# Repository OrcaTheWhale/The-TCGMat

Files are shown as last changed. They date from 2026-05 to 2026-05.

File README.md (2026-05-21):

# The-TCGMat
A mat that is designed for TCG! Well, mostly just One Piece TCG and Riftbound.

Notice:
Under "StepFiles", and in the Onshape document, certain parts have "O" at the end of their names. This means that part is optional. If  you would like to save on filament, then you can skip printing the optional parts.

I also assume you have jumper wires. If you don't, what are you doing.

**What is this?**

The TCGMat is a 3D - printable (and thick) mat that integrates LEDS and a screen into your TCG experience! With LED settings, you can turn change the color of your border, alongside the Leader/Legend card border. You can also pass your turn, turning the border leds to red!

The TCGMat has a few built in settings for basic level play, such as Riftbound settings, One Piece settings, and LED settings. 

It also contains **NO** screws, meaning it's literally attach-and-play.

**Why would I use this?**

Great question! Why would you? It IS 2kg of filament... But think about it! Just like the Zine page says, you can absolutely mog your opponent! Think about it. It's a tournament. Or a local game tournament. Your opponent takes out his cool art mat of DaVinci Starry Night Pikachu. And then, you whip out - this thick, 2kg piece of rectangle. Will people think you look stupid? Mmm, maybe. But then, they'll see the LED colors shine at the borders. They'll still think it's stupid, of course, but now, it looks _cool_ stupid. The amount of aura you'll have with the mat will provide a sense of dominance.

**How does this work?**

You take the parts and attach them, no screws needed. You link them using four or two link rectangles given in the CAD/StepFiles. 
For the code, well... It's built based off of pure hopes and dreams. It is about 800 lines of absolutely disgustingly unoptimized code. 
There are three buttons: On/Off, Config, and Action. On/Off is self explanatory. Config is for the settings, it allows scrolling through different options. Action selects those options.

**Why did I make this?**

Great question, reader! I made this to try communication between microcontrollers. Originally, the idea was to have two mats being able to connect to each other and share info, but I gave up on that idea after realising I would have to change... some things... But, the option is still there, if you want to try to go for it yourself.

The reference Transf- (it cut off) is for magnetic pogo pin connectors. You can check the schematic, but RX is labeled for you, if you are going for TX/RX communicaton. A resistor is also already placed on the TX line. If you want to try for communication, go for it!

But I also made this cause my friends play One Piece / Riftbound TCG. I, myself only play Riftbound, but I thought it'd be cooler to have more than one game option on the TCG Mat. I also have no idea how to play other TCG's, so that's why the only options are Riftbound and One Piece.

**For the TCG fans:**

Take a shower.

Zine Page!



PCB:





Schematic:


CAD Model:


CAD: https://cad.onshape.com/documents/c90b06010f75d3568477ea12/w/fd36c3df957e31bf29fadb32/e/bceb6737e14c83207b7cbead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

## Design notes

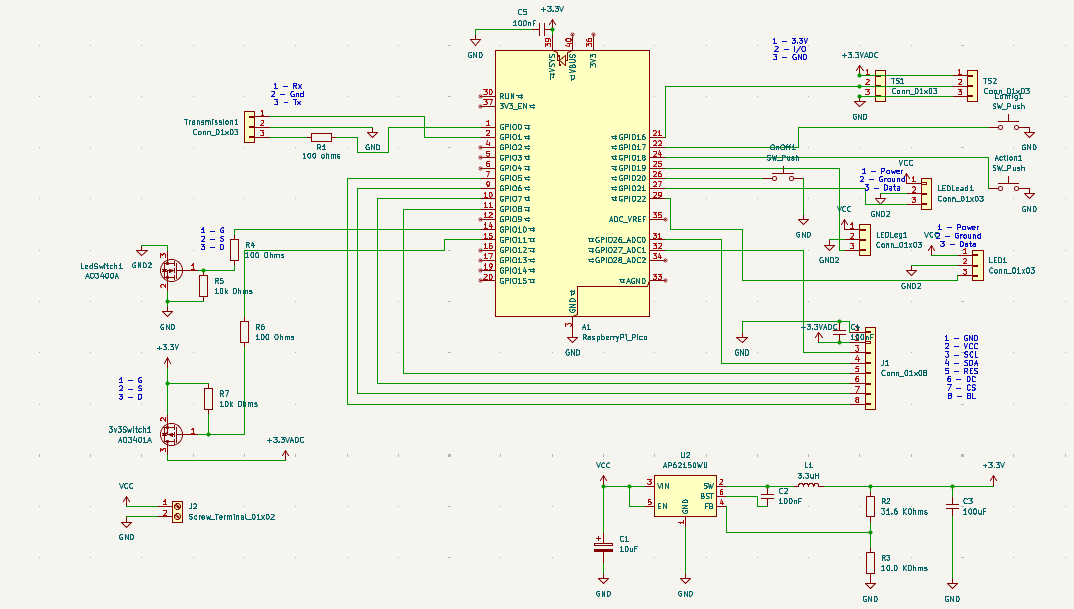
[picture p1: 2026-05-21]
Assets/Schematic.png

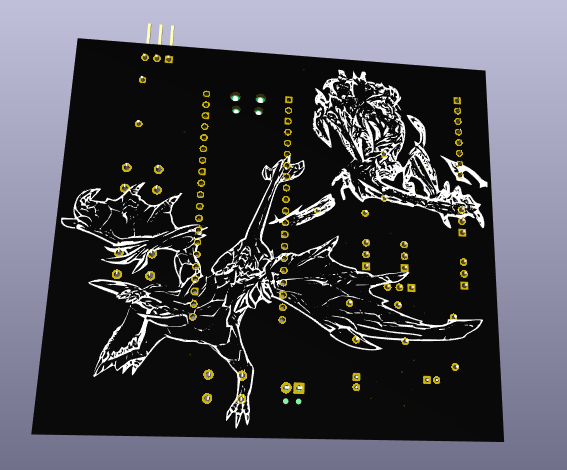
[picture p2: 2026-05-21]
Assets/PCBBackside.png

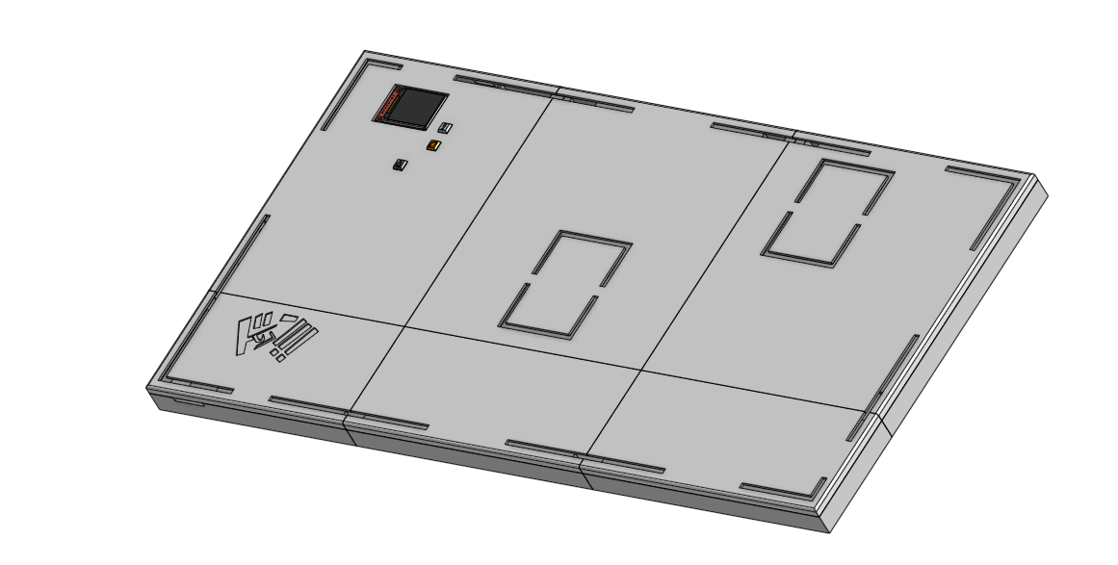
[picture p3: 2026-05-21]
Assets/CAD_Model.png

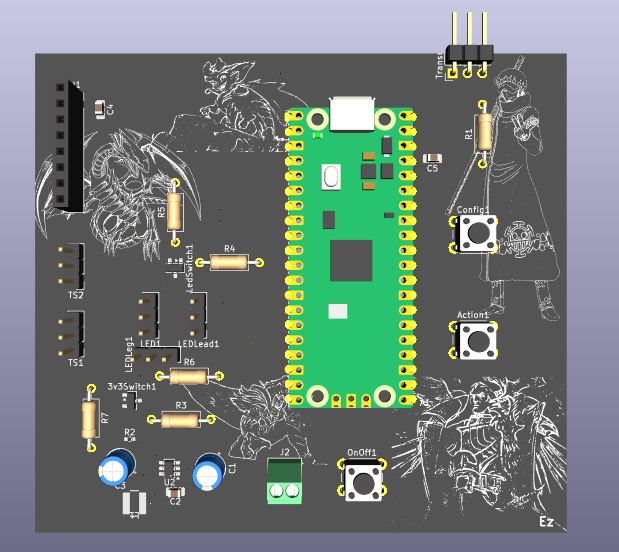
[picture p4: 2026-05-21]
Assets/FrontsidePCB.png

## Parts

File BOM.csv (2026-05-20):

Component | Quantity | Price (CAD) | REF | Link
TCGMat PCB (JLCPCB) | 1 | 10.97
COB LED 2 meters | 1 | 23.40 |  | https://www.aliexpress.com/item/1005005046710332.html?curPageLogUid=nG6Y9pPg4gLo
TFT Display | 1 | 4.67 | J1 | https://www.aliexpress.com/item/1005006139989470.html?curPageLogUid=zueyNqq3oKLD
Touch Sensors | 1-2 | 3.24 | TouchSensor1/TouchSensor2Ghost | https://www.aliexpress.com/item/1005006246380749.html?curPageLogUid=ayPRraC3GVgy
31.6k Ohms Resistor | 1 | 0.17 | C2 | https://www.digikey.ca/en/products/detail/panasonic-industry/ERA-2AEB3162X/2026187
N-Channel Mosfet | 1 | 0.80 | LedSwitch1 | https://www.digikey.ca/en/products/detail/alpha-omega-semiconductor-inc/AO3400A/1855772
P-Channel Mosfet | 1 | 0.80 | 3v3Switch1 | https://www.digikey.ca/en/products/detail/alpha-omega-semiconductor-inc/AO3401A/1855773
Charging Module, 12v Boost With Box | 1 | 3.96 |  | https://www.aliexpress.com/item/1005005631366128.html?curPageLogUid=n5X83sLfYBQ7
3.3 uH Inductor | 1 | 0.27 | L1 | https://www.digikey.ca/en/products/detail/taiyo-yuden/NRS4018T3R3MDGJ/2648970
Buck IC | 1 | 0.62 | U2 | https://www.digikey.ca/en/products/detail/diodes-incorporated/AP62150WU-7/13161380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
100 Ohms Resistor (Kit) | 3 |  | R1, R4, R6
10k Ohms Resistor (Kit) | 1 | 5.75 | R3, R5, R7 | https://www.aliexpress.com/item/1005011772534173.html?curPageLogUid=PY4tIajfEo4w
100 nF Capacitor SMD | 2 | 3.55 | C2, C4 | https://www.aliexpress.com/item/32964553793.html?curPageLogUid=D9Skj0LdTYfY
10 uF Capacitor TH | 1 | 3.53 | C1 | https://www.aliexpress.com/item/1005002524973878.html?curPageLogUid=nXsUsC5NtFek
100 uF Capacitor TH | 1 | 4.07 | C3 | https://www.aliexpress.com/item/1005002524973878.html?curPageLogUid=nXsUsC5NtFek
Screw Terminal 2.54mm | 2 | 2.38 | J2, Code1 | https://www.aliexpress.com/item/4000867583795.html?curPageLogUid=PtJUplS5tBPZ
Pin Header 2.54mm 01x40 (snap off) | 1 | 6.50 | (LED1)/(LEDLead/Leg1) | https://www.aliexpress.com/item/1005007564228387.html?curPageLogUid=1ko1KDBTmACq
Switch Buttons 6x6mm | 3 | 2.29 | OnOff1, Config1, Action1 | https://www.aliexpress.com/item/1005006046180384.html?curPageLogUid=pfAIYvwROHL0
Raspberry Pi Pico | 1 | 4.59 |  | https://www.digikey.ca/en/products/detail/raspberry-pi/SC0915/13624793
PLA Filament (1kg) | 2 | 51.98 |  | https://ca.store.bambulab.com/products/pla-basic-filament?id=43115681841392
Digikey Shipping | 1 | 25.00
Tax |  | 17.36
Total: |  | 164.93

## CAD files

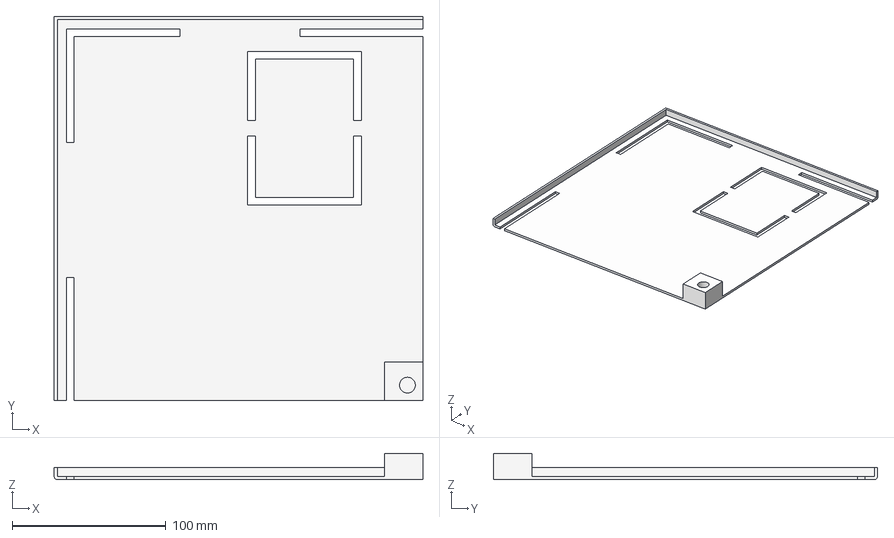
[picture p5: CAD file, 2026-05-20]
StepFiles/Part Studio 1 - TMat1.step
240.0 x 250.0 x 17.0 mm

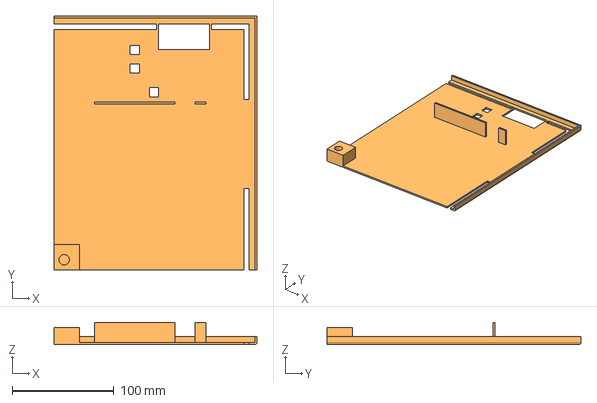
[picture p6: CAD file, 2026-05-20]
StepFiles/Part Studio 1 - TMat6.step
200.0 x 250.0 x 22.0 mm

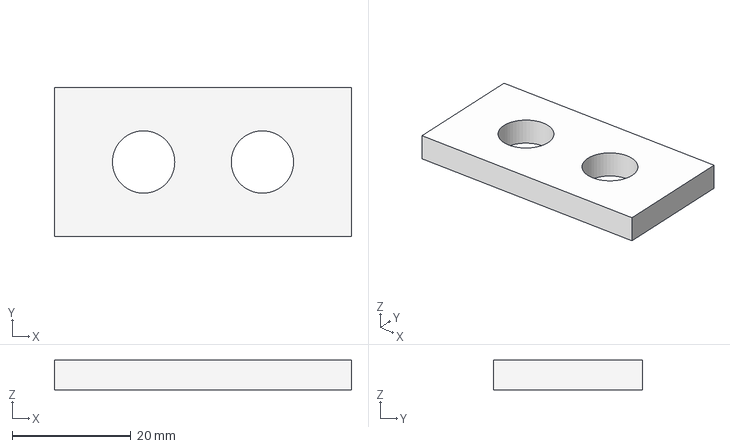
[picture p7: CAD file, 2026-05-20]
StepFiles/Part Studio 1 - 2Link.step
50.0 x 25.0 x 5.00 mm

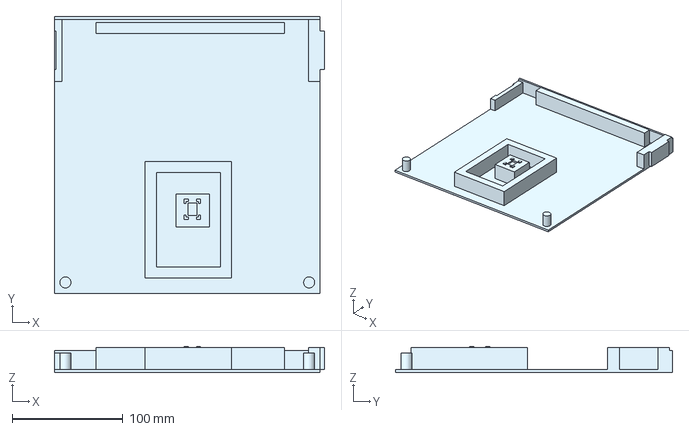
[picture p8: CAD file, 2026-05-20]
StepFiles/Part Studio 1 - BMat4.step
244.0 x 250.0 x 23.5 mm

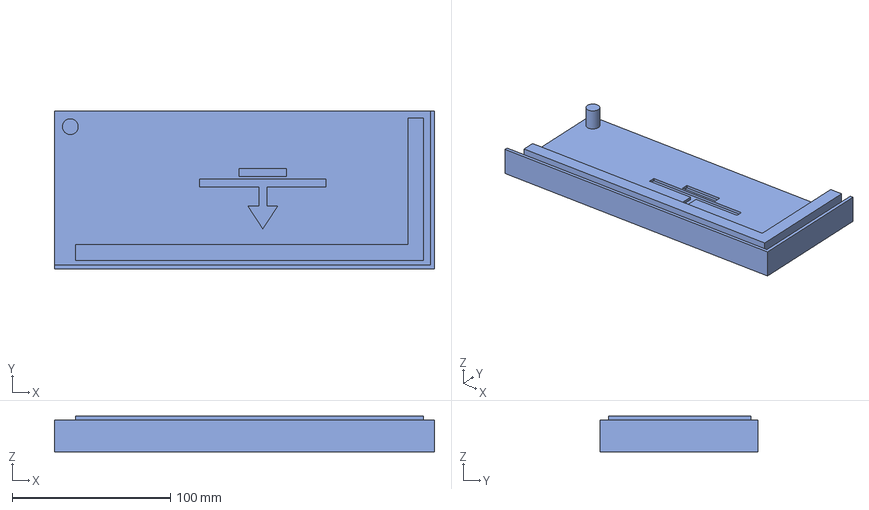
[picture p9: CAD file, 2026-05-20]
StepFiles/Part Studio 1 - BMat2O.step
240.0 x 100.0 x 22.5 mm

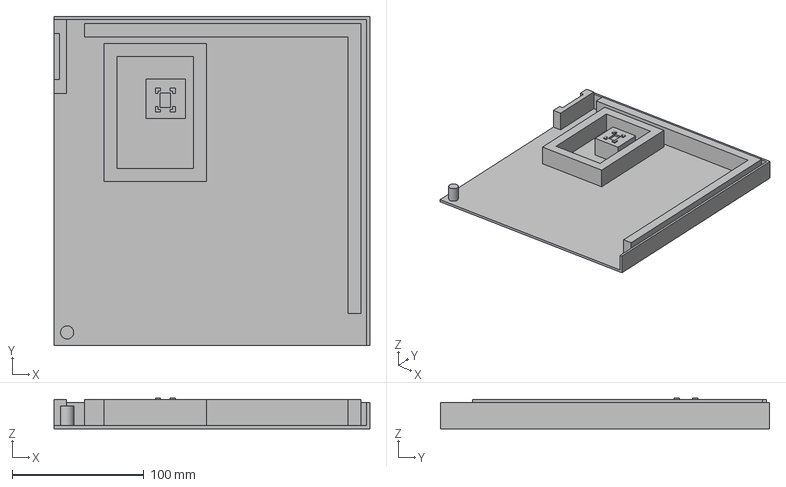
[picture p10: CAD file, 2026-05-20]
StepFiles/Part Studio 1 - BMat6.step
240.0 x 250.0 x 23.5 mm

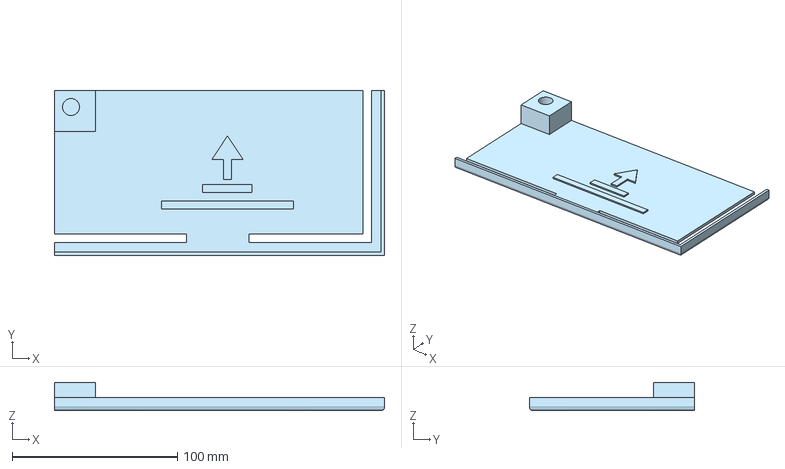
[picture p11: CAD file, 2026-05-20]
StepFiles/Part Studio 1 - TMat5O.step
200.0 x 100.0 x 17.0 mm

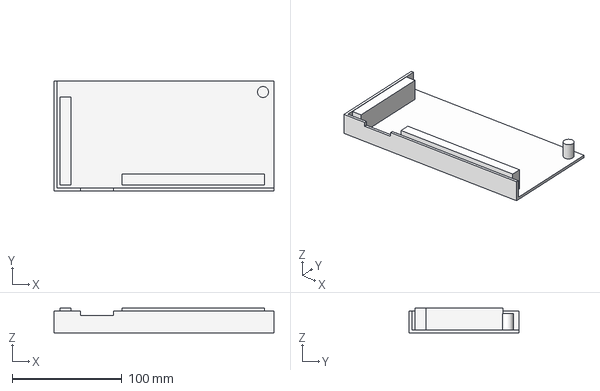
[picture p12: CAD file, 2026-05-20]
StepFiles/Part Studio 1 - BMat3O.step
200.0 x 100.0 x 22.5 mm

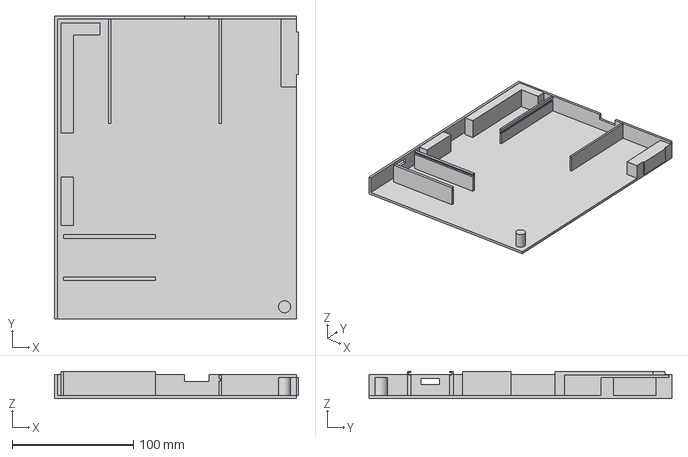
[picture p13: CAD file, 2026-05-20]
StepFiles/Part Studio 1 - BMat1.step
201.5 x 250.0 x 22.5 mm

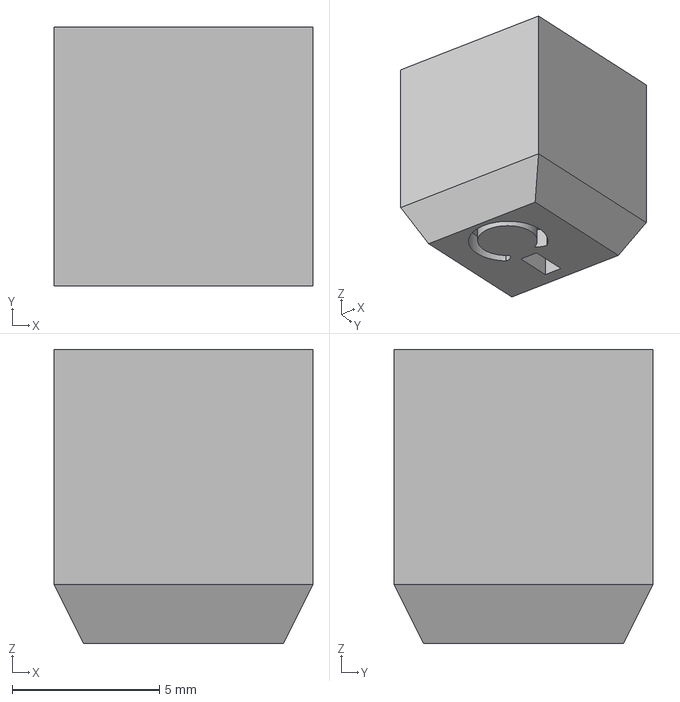
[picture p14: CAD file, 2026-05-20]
StepFiles/Part Studio 1 - OnOff Button.step
8.80 x 8.80 x 10.0 mm

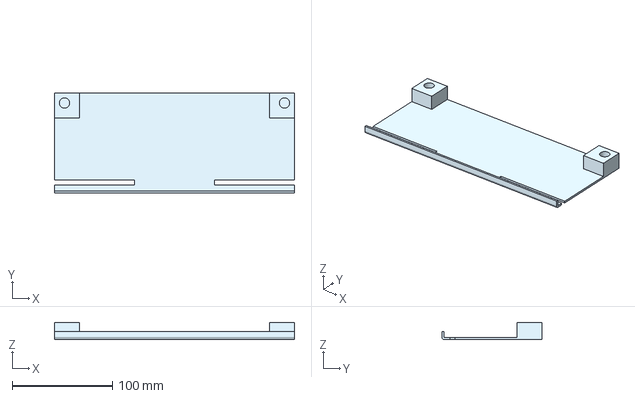
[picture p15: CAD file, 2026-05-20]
StepFiles/Part Studio 1 - TMat2O.step
240.0 x 100.0 x 17.0 mm

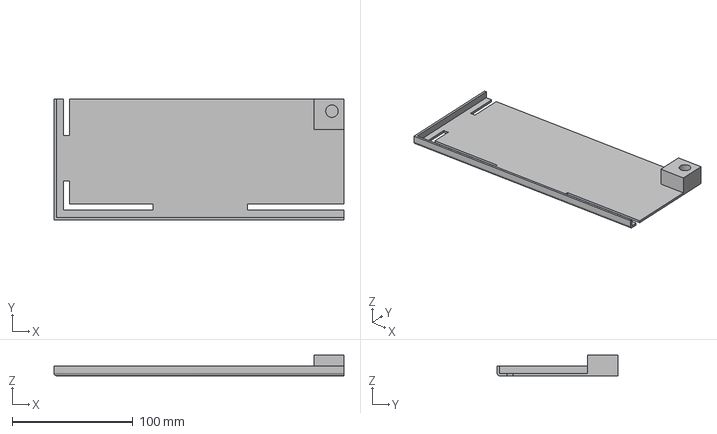
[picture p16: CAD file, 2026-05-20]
StepFiles/Part Studio 1 - TMat3O.step
240.0 x 100.0 x 17.0 mm

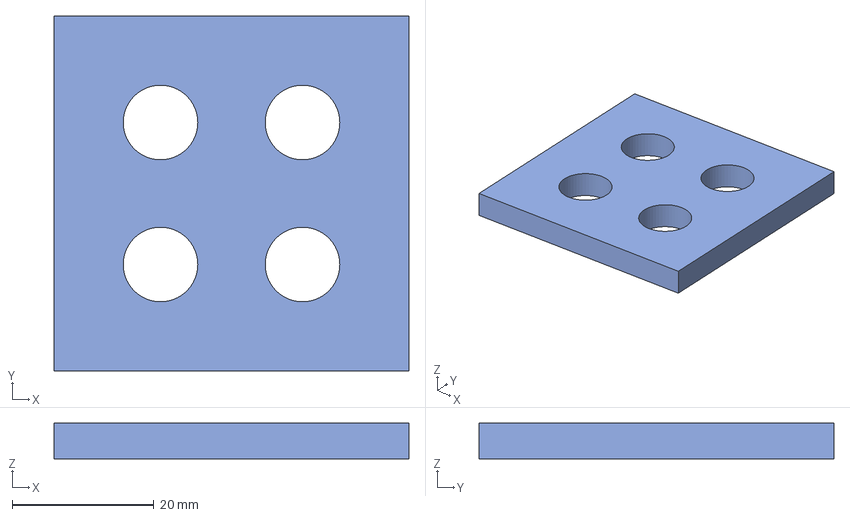
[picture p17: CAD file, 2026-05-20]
StepFiles/Part Studio 1 - FourLink.step
50.0 x 50.0 x 5.00 mm

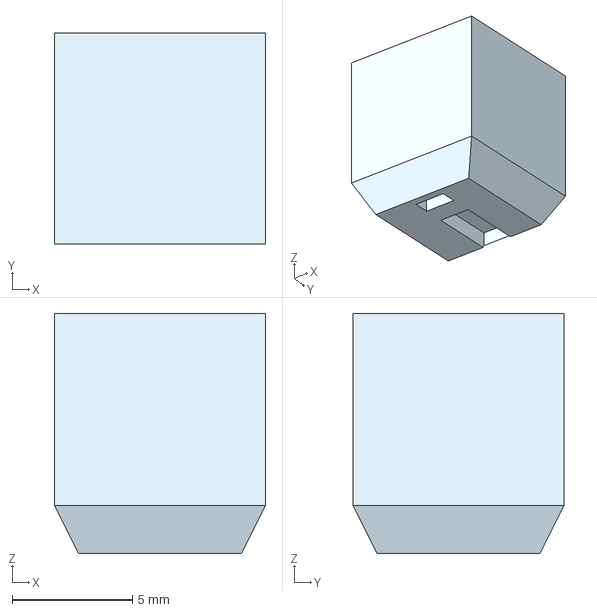
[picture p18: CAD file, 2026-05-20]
StepFiles/Part Studio 1 - Action Button.step
8.80 x 8.80 x 10.0 mm

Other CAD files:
StepFiles/Part Studio 1 - TMat4.step
StepFiles/Part Studio 1 - Config Button.step
StepFiles/Part Studio 1 - BMat5O.step

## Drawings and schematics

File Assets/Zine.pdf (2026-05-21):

# The TCGMat

### Thing

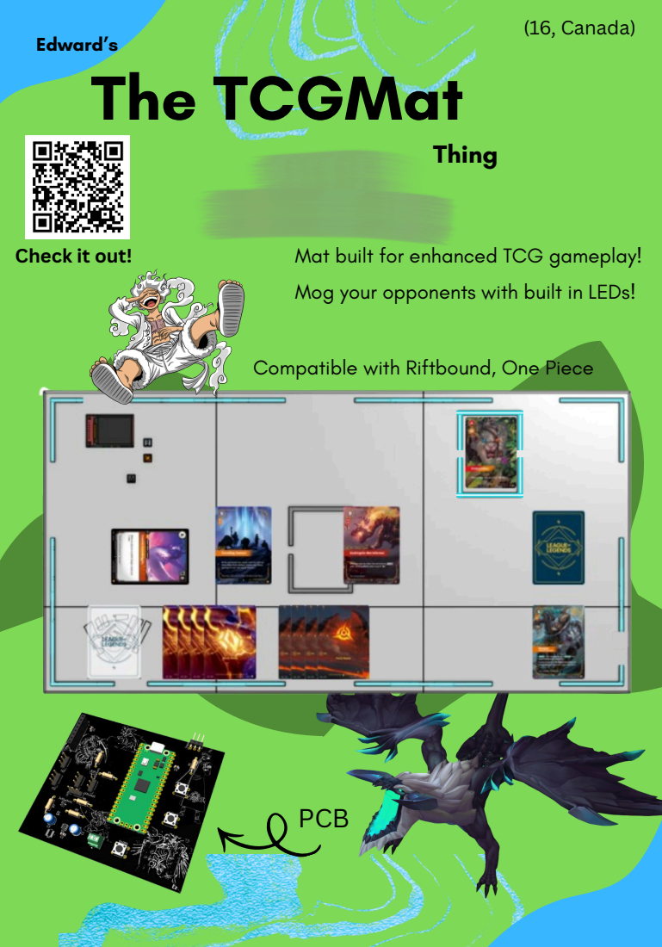
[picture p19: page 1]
Edward’s; PCB; (16, Canada)

Check it out!

Mat built for enhanced TCG gameplay!
Mog your opponents with built in LEDs!

Compatible with Riftbound, One Piece

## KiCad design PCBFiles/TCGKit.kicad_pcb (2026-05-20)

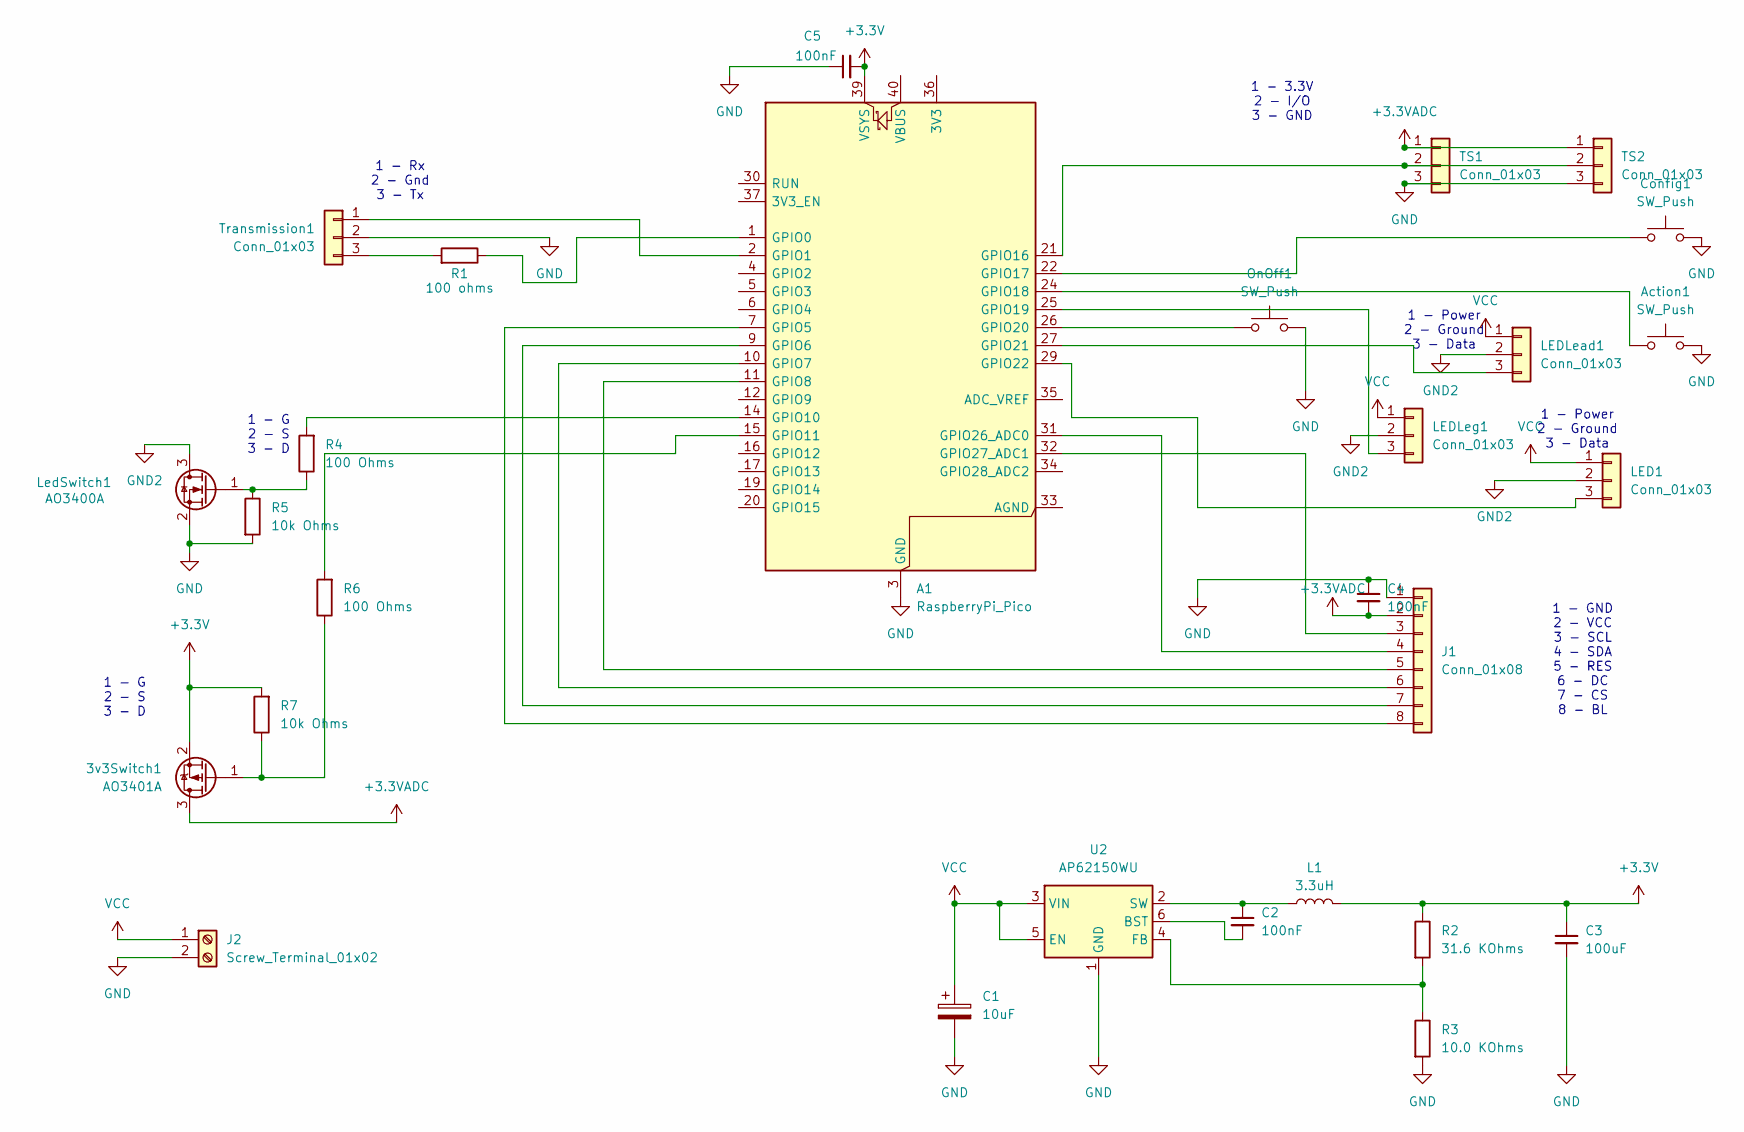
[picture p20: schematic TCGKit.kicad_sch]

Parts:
3v3Switch1: AO3401A; SOT-23
A1: RaspberryPi_Pico; RaspberryPi_Pico_Common_Unspecified
Action1: SW_Push; SW_PUSH_6mm
C1: 10uF; CP_Radial_D5.0mm_P2.00mm
C2, C4, C5: 100nF; C_0805_2012Metric_Pad1.18x1.45mm_HandSolder
C3: 100uF; CP_Radial_D5.0mm_P2.00mm
Config1: SW_Push; SW_PUSH_6mm
J1: Conn_01x08; PinSocket_1x08_P2.54mm_Vertical
J2: Screw_Terminal_01x02; TerminalBlock_Phoenix_MPT-0,5-2-2.54_1x02_P2.54mm_Horizontal
L1: 3.3uH; IND_TAIYO_NRS4018_TAY
LED1: Conn_01x03; PinHeader_1x03_P2.54mm_Vertical
LEDLead1: Conn_01x03; PinHeader_1x03_P2.54mm_Vertical
LEDLeg1: Conn_01x03; PinHeader_1x03_P2.54mm_Vertical
LedSwitch1: AO3400A; SOT-23
OnOff1: SW_Push; SW_PUSH_6mm
R1: 100 ohms; R_Axial_DIN0207_L6.3mm_D2.5mm_P10.16mm_Horizontal
R2: 31.6 KOhms; R_0402_1005Metric_Pad0.72x0.64mm_HandSolder
R3: 10.0 KOhms; R_Axial_DIN0207_L6.3mm_D2.5mm_P10.16mm_Horizontal
R4, R6: 100 Ohms; R_Axial_DIN0207_L6.3mm_D2.5mm_P10.16mm_Horizontal
R5, R7: 10k Ohms; R_Axial_DIN0207_L6.3mm_D2.5mm_P10.16mm_Horizontal
TS1, TS2: Conn_01x03; PinHeader_1x03_P2.54mm_Vertical
Transmission1: Conn_01x03; PinHeader_1x03_P2.54mm_Horizontal
U2: AP62150WU; TSOT-23-6

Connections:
+3.3V: 3v3Switch1.2 (S), A1.39 (VSYS), C3.1, C5.2, L1.2, R2.1, R7.2
+3.3VADC: 3v3Switch1.3 (D), C4.2, J1.2, TS1.1, TS2.1
GND: A1.3 (GND), A1.8 (GND), A1.13 (GND), A1.18 (GND), A1.23 (GND), A1.28 (GND), A1.38 (GND), Action1.2, C1.2, C3.2, C4.1, C5.1, Config1.2, J1.1, J2.2, LedSwitch1.2 (S), OnOff1.2, R3.2, R5.2, TS1.3, TS2.3, Transmission1.2, U2.1 (GND)
GND2: LED1.2, LEDLead1.2, LEDLeg1.2, LedSwitch1.3 (D)
unnamed: 3v3Switch1.1 (G), R6.1, R7.1
unnamed: A1.1 (GPIO0), R1.1
unnamed: A1.2 (GPIO1), Transmission1.1
unnamed: A1.7 (GPIO5), J1.8
unnamed: A1.9 (GPIO6), J1.7
unnamed: A1.10 (GPIO7), J1.6
unnamed: A1.11 (GPIO8), J1.5
unnamed: A1.14 (GPIO10), R4.2
unnamed: A1.15 (GPIO11), R6.2
unnamed: A1.21 (GPIO16), TS1.2, TS2.2
unnamed: A1.22 (GPIO17), Config1.1
unnamed: A1.24 (GPIO18), Action1.1
unnamed: A1.25 (GPIO19), LEDLeg1.3
unnamed: A1.26 (GPIO20), OnOff1.1
unnamed: A1.27 (GPIO21), LEDLead1.3
unnamed: A1.29 (GPIO22), LED1.3
unnamed: A1.31 (GPIO26_ADC0), J1.4
unnamed: A1.32 (GPIO27_ADC1), J1.3
unnamed: LedSwitch1.1 (G), R4.1, R5.1
unnamed: R1.2, Transmission1.3
unnamed: C2.2, U2.6 (BST)
unnamed: R2.2, R3.1, U2.4 (FB)
unnamed: C2.1, L1.1, U2.2 (SW)
VCC: C1.1, J2.1, LED1.1, LEDLead1.1, LEDLeg1.1, U2.3 (VIN), U2.5 (EN)

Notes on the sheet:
1 - Power 2 - Ground 3 - Data
1 - 3.3V 2 - I/O 3 - GND
1 - Rx 2 - Gnd 3 - Tx
1 - GND 2 - VCC 3 - SCL 4 - SDA 5 - RES 6 - DC 7 - CS 8 - BL
1 - G 2 - S 3 - D

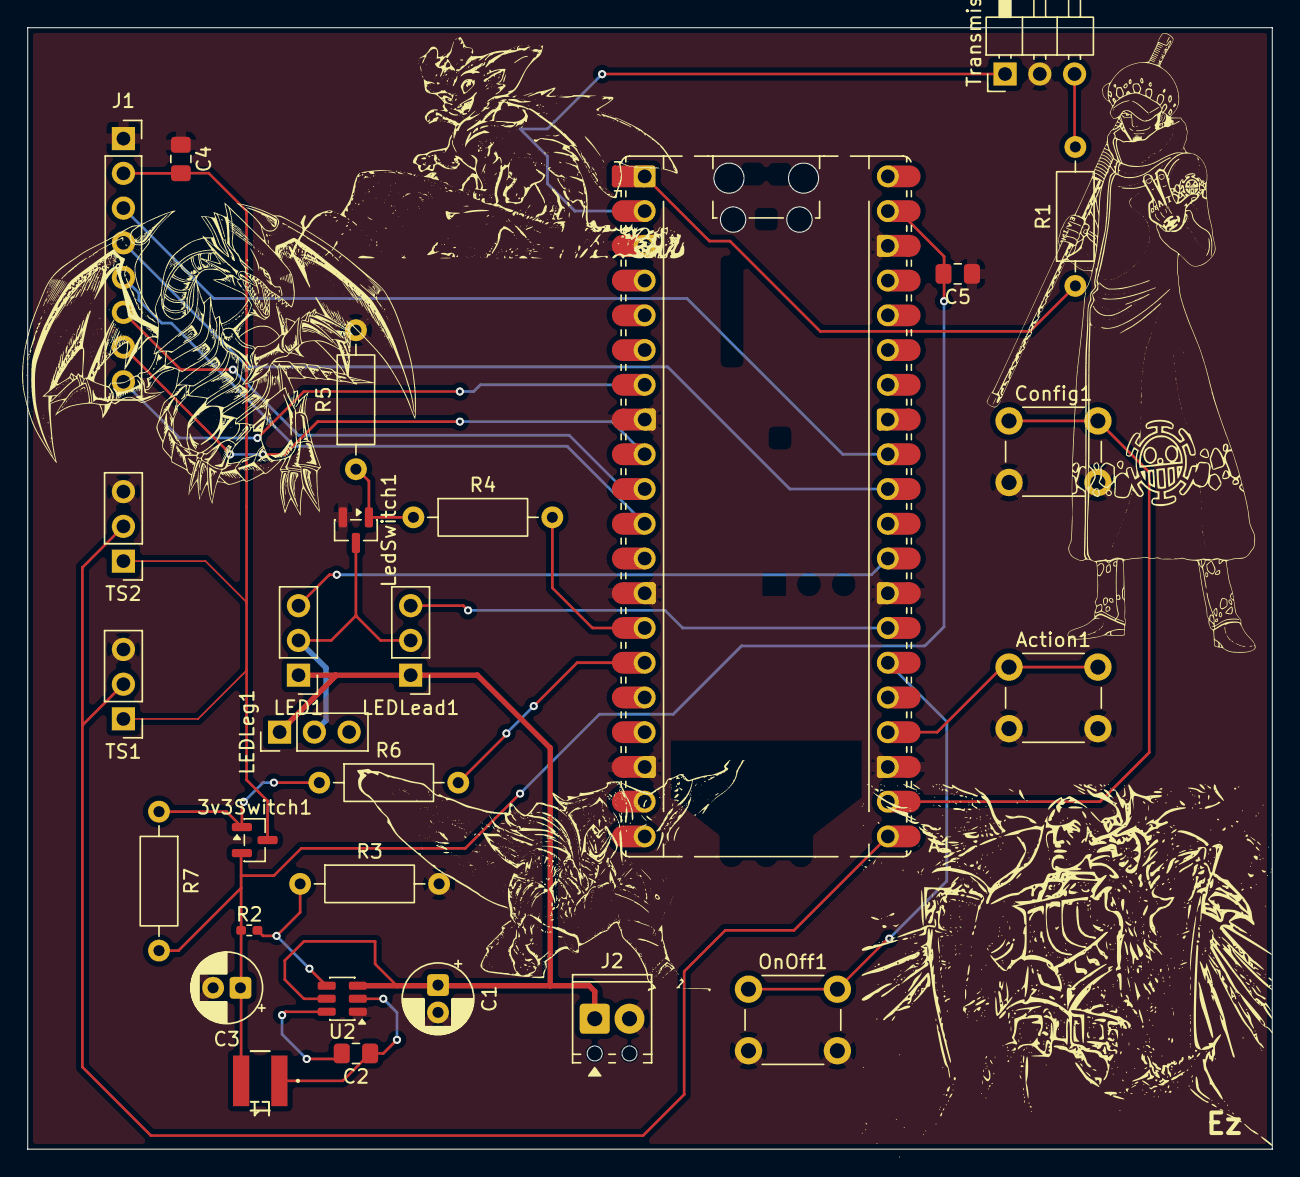
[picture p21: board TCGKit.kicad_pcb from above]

Board: 4 copper layers, 91.0 x 82.0 mm, 28 parts (0 on the bottom side), 28 nets.

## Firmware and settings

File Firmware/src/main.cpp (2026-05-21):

#include <Arduino.h>
#include <Adafruit_GFX.h>    // Core graphics library
#include <Adafruit_ST7735.h> // Hardware-specific library for ST7735
#include "Adafruit_miniTFTWing.h"
#include <SPI.h>
#include <FastLED.h>

#define NUM_LEDSBORDER 1 // change
#define NUM_LEDSLEGEND 1 // change
#define NUM_LEDSLEADER 1 // change

#define DATA_PINBORDER 22
#define DATA_PINLEGEND 19
#define DATA_PINLEADER 21

/*
const int ledborder = 22;
const int legendborder = 19;
const int leaderborder = 21;
*/
CRGB ledsborder[NUM_LEDSBORDER];
CRGB ledslegend[NUM_LEDSLEGEND];
CRGB ledsleader[NUM_LEDSLEADER];


CRGB colors[] = {CRGB::White, CRGB::Green, CRGB::Blue, CRGB::Black};


#define TFT_RST 8

#define TFT_CS 6
#define TFT_DC 7

Adafruit_ST7735 tft = Adafruit_ST7735(TFT_CS,  TFT_DC, TFT_RST);

// put function declarations here:

const int onoff = 20;
const int config = 17;
const int action = 18;

const int ledswitch = 10;
const int threeswitch = 11;

const int touch = 16;

static String state = "Default";
static String selectstate = "left";
static String settingsstate = "Menu";

//debounce for config
static bool debounce = false;
static bool ledstate = false;


static int points;
static int xp;
static int riftboundthreshhold = 8;
static bool aspirants = false;
static bool activablelegend = false;



static bool isyourturn = false;
static bool islegendexhausted = false;

//debounce for touch sensors
static bool debouncetwo = false;

//debounce for action
static bool debounceaction = false;

//debounce for onoff
static bool debounceonoff = false;

static bool onoffstate = false;

static bool screenneedsupdate = false;

static CRGB bordercolor = CRGB::White;
//To Do:
//Led settings:
//On/Off  - done
//Led Colors - done
//Led turns different color based on turn - done I think
//Turn system: - need to do

// How will player know?
// Option 1: Pass turn button
// Option 2: No other idea
//Touch sensor --> led on/off
//Brightness

//To do today:
//Rewrite returncolor(), no need for it - done
//Turn based mode - done

//Connection mode? -- Nah, would have to redisgn PCB / Mat


static void ledhandling(String state) {
  if (state == "Turn") {
    if (isyourturn) {

      ledsborder[0] = CRGB::Green;
      islegendexhausted = false;
    //border color --> your color chosen
  } else {
    //border color --> red
    ledsborder[0] = CRGB::Red;
    
  }

  } else if (state == "Leader_Legend") {
    if (activablelegend) {
      if (islegendexhausted) {
        if (state == "Riftbound") {
          ledslegend[0] = CRGB::Red;
        } else if (state == "One Piece") {
          ledsleader[0] = CRGB::Red;
        }
        //border color --> exhausted color
        
      } else {  
        //border color --> legend color
        if (state == "Riftbound") {
          ledslegend[0] = bordercolor;
        } else if (state == "One Piece") {
          ledsleader[0] = bordercolor;
        }

      }
      //border color --> your color chosen
    } else {
      //border color --> chosen color
      if (state == "Riftbound") {
        ledslegend[0] = bordercolor;
      }
      if (state == "One Piece") {
        ledsleader[0] = bordercolor;
      }
    }
  }
  

}

static void wingame(boolean value) {
  tft.fillScreen(ST77XX_BLACK);
  tft.setCursor(0, 0);
  tft.setTextColor(ST77XX_WHITE);
  tft.setTextSize(1);
  if (value) {
    tft.println("You win!");
  } else {
    tft.println("You lose!");
  }
  delay(5000);
  state = "Default";
  points = 0;
}

static void selectionarrows(String ref) {
  tft.fillScreen(ST77XX_BLACK);
  if (ref == "Riftbound") {
    if (selectstate == "up") {
      tft.setCursor(20, 20);
      tft.println("<");
    } else if (selectstate == "middle") {
      tft.setCursor(20, 40);
      tft.println("<");
    } else if (selectstate == "down") {
      tft.setCursor(20, 60);
      tft.println("<");
    } else if (selectstate == "downonemoretime") {
      tft.setCursor(20, 80);
      tft.println("<");
    }
  } else if (ref == "One Piece") {
    if (selectstate == "up") {
      tft.setCursor(20, 20);
      tft.println("<");
    } else if (selectstate == "middle") {
      tft.setCursor(20, 40);
      tft.println("<");
    } else if (selectstate == "down") {
      tft.setCursor(20, 60);
      tft.println("<");
    }

  } else if (ref == "Settings") {
    if (settingsstate == "Back") {
      tft.setCursor(20, 0);
      tft.println("<");
    } else if (settingsstate == "Led") {
      tft.setCursor(20, 20);
      tft.println("<");
    } else if (settingsstate == "Riftbound") {
      tft.setCursor(20, 40);
      tft.println("<");
    } else if (settingsstate == "One Piece") {
      tft.setCursor(20, 60);
      tft.println("<");
    }


    //if we're calling it with the settings state, we check which one, I think

    //we need to make sure we're in settings --> subsettings mode
    //CALL LED SETTINGS WHEN IN LED SETTINGS, AND FOR THE REST THE SAME
  } else if (ref == "LedSettings") {
    if (settingsstate == "Back") {
      tft.setCursor(20, 0);
      tft.println("<");
    } else if (settingsstate == "LedOnOff") {
      tft.setCursor(20, 20);
      tft.println("<");
    } else if (settingsstate == "Color") {
      tft.setCursor(20, 40);
      tft.println("<");
    } else if (settingsstate == "Brightness") {
      tft.setCursor(20, 60);
      tft.println("<");
    }

  } else if (ref == "Color") {
    if (settingsstate == "White") {
      tft.setCursor(20, 20);
      tft.println("<");
    } else if (settingsstate == "Green") {
      tft.setCursor(20, 40);
      tft.println("<");
    } else if (settingsstate == "Blue") {
      tft.setCursor(20, 60);
      tft.println("<");
    } else if (settingsstate == "Black") {
      tft.setCursor(20, 80);
      tft.println("<");
    }
  } else if (ref == "RiftboundSettings") {
    if (settingsstate == "Back") {
      tft.setCursor(20, 0);
      tft.println("<");
    } else if (settingsstate == "Aspirants") {
      tft.setCursor(20, 20);
      tft.println("<");
    } else if (settingsstate == "ActivableLegend") {
      tft.setCursor(20, 40);
      tft.println("<");
    }

  } else if (ref == "OnePieceSettings") {
    if (settingsstate == "Back") {
      tft.setCursor(20, 0);
      tft.println("<");
    } else if (settingsstate == "Lives") {
      tft.setCursor(20, 20);
      tft.println("<");
    }
  } else if (ref == "Default") {
    if (selectstate == "left") {
      tft.setCursor(20, 20);
      tft.println("<");
    } else if (selectstate == "middle") {
      tft.setCursor(20, 40);
      tft.println("<");
    } else if (selectstate == "right") {
      tft.setCursor(20, 60);
      tft.println("<");
    }
  }

}
void setup() {
  // put your setup code here, to run once:
  Serial.begin(115200);
  state = "Default";
  tft.initR(INITR_BLACKTAB); // Initialize a ST7735S chip, black tab
  tft.fillScreen(ST77XX_BLACK);

  pinMode(onoff, INPUT_PULLUP);
  pinMode(config, INPUT_PULLUP);
  pinMode(action, INPUT_PULLUP);

  pinMode(ledswitch, OUTPUT);
  pinMode(threeswitch, OUTPUT);

  pinMode(touch, INPUT);

  FastLED.addLeds<WS2812, DATA_PINBORDER, GRB>(ledsborder, NUM_LEDSBORDER);
  FastLED.addLeds<WS2812, DATA_PINLEGEND, GRB>(ledslegend, NUM_LEDSLEGEND);
  FastLED.addLeds<WS2812, DATA_PINLEADER, GRB>(ledsleader, NUM_LEDSLEADER);

}

void loop() {
  // put your main code here, to run repeatedly:

  if (digitalRead(onoff) == LOW) {
    if (debounceonoff == false) {
      debounceonoff = true;
      if (onoffstate) {
        onoffstate = false;
        digitalWrite(ledswitch, HIGH);
        digitalWrite(threeswitch, LOW);
      } else {
        onoffstate = true;
        digitalWrite(ledswitch, LOW);
        digitalWrite(threeswitch, HIGH);
      }
      
    }
    delay(50);
  } else {
    debounceonoff = false;
  } 



  //Screen
  if (state == "Default") {
    if (screenneedsupdate) {
      tft.setCursor(0, 0);
      tft.setTextColor(ST77XX_WHITE);
      tft.setTextSize(1);
      tft.println("Select gamemode: ");
      tft.setCursor(0, 20);
      tft.println("Riftbound");
      tft.setCursor(0, 40);
      tft.println("One Piece");
      tft.setCursor(0, 60);
      tft.println("Settings");
      selectionarrows("Default");
      screenneedsupdate = false;
    }
    
    
    

    if(digitalRead(config) == LOW) {
      if (debounce == false) {

        debounce = true;
        screenneedsupdate = true;
        if (selectstate == "left") {
          selectstate = "middle"; 
        } else if (selectstate == "middle") {
          selectstate = "right";
        } else if (selectstate == "right") {
          selectstate = "left";
        }
    
      } 
    
      
      delay(50);
    } else {
      debounce = false;
    }

    if (digitalRead(action) == LOW) {
      if (state == "Default") {
      if (debounceaction == false) {
        debounceaction = true;
        screenneedsupdate = true;

        //remove selectionarrows in a sec
        if (selectstate == "left") {
          state = "Riftbound";
          ledsleader[0] = CRGB::Black;
          
          points = 0;
          xp = 0;
          selectstate = "up";
        } else if (selectstate == "middle") {
          state = "One Piece";
          //idk bruh
          ledslegend[0] = CRGB::Black;
          points = points;
          selectstate = "up";
        } else if (selectstate == "right") {
          state = "Settings";
          selectstate = "up";
          settingsstate = "Back";
          
        }

        //Make sure the state isn't set for something previously selected, so that the screen doesn't mess up
        selectstate = "";

      } 

    } 
    delay(50);
  } else {
    debounceaction = false;
  }

  }

  //We need a way to make the user know which selection is happening
  //Arrows like this <
  //How?
  //Write unnecessary boolean values
  //Or compare the selectstate with the current option, write the arrows on that index

  if (state == "Riftbound") {
    if (screenneedsupdate) {
      screenneedsupdate = false;
      tft.fillScreen(ST77XX_BLACK);
      tft.setCursor(0, 0);
      tft.setTextColor(ST77XX_WHITE);
      tft.setTextSize(1);
      tft.println("Riftbound");
      tft.setCursor(0, 20);
      tft.println("Points:" + String(points));
      tft.setCursor(0, 40);
      tft.println("XP:" + String(xp));
      tft.setCursor(0, 60);
      tft.println("Pass Turn");
      tft.setCursor(0, 80);
       selectionarrows("Riftbound");
      tft.println("Exit");
    }
    
    

    if (digitalRead(config) == LOW) {
      if (debounce == false) {
        debounce = true;
        screenneedsupdate = true;
        if (selectstate == "up") {
          selectstate = "middle"; 

        } else if (selectstate == "middle") {
          selectstate = "down";
        } else if (selectstate == "down") {
          selectstate = "downonemoretime";
        } else if (selectstate == "downonemoretime") {
          selectstate = "up";
        }
      }
      delay(50);
    } else {
      debounce = false;
    }
   
    if (digitalRead(action) == LOW) {
      screenneedsupdate = true;
      if (debounceaction == false) {
        debounceaction = true;
        if (selectstate == "up") {

          points++;
          if (points >= riftboundthreshhold) {
            wingame(true);
          }
        } else if (selectstate == "middle") {
          xp++;
        } else if (selectstate == "down") {
          state = "WaitingForTurn";
        } else if (selectstate == "downonemoretime") {
          state = "Default";
        }
      }
      delay(50);
    } else {
      debounceaction = false;
    }


  } else if (state == "One Piece") {
    if (screenneedsupdate) {
      tft.fillScreen(ST77XX_BLACK);
      tft.setCursor(0, 0);
      tft.setTextColor(ST77XX_WHITE);
      tft.setTextSize(1);
      tft.println("One Piece");
      tft.setCursor(0, 20);
      tft.println("Lives: " + String(points));
      tft.setCursor(0, 40);
      tft.println("Pass Turn");
      tft.setCursor(0, 60);
      tft.println("Exit");
      
      selectionarrows("One Piece");
      screenneedsupdate = false;
    }
    

    if (digitalRead(config) == LOW) {
      if (debounce == false) {
        debounce = true;
        screenneedsupdate = true;
        if (selectstate == "up") {
          selectstate = "middle"; 

        } else if (selectstate == "middle") {
          selectstate = "down";
        } else if (selectstate == "down") {
          selectstate = "up";
        }
      }
      delay(50);
    } else {
      debounce = false;
    }

    if (digitalRead(action) == LOW) {
      if (debounceaction == false) {
        debounceaction = true;
        screenneedsupdate = true;
        if (selectstate == "up") {
          points--;
          if (points < 0) {
            wingame(false);
          }
        } else if (selectstate == "down") {
          state = "Default";
        }
      }
      delay(50);
    } else {
      debounceaction = false;
    }

    //code here later
  } else if (state == "Settings") {

    if (settingsstate == "Menu") {   
      if (screenneedsupdate) {
      tft.fillScreen(ST77XX_BLACK);
      tft.setCursor(0, 0);
      tft.setTextColor(ST77XX_WHITE);
      tft.setTextSize(1);
      tft.println("Back");
      tft.setCursor(0, 20);
      tft.println("LED");
      tft.setCursor(0, 40);
      tft.println("Riftbound");
      tft.setCursor(0, 60);
      tft.println("One Piece");
      selectionarrows("Settings");
      screenneedsupdate = false;
      } 
      
      //Scrolling through options
      if (digitalRead(config) == LOW) {
        if (debounce == false) {
          debounce = true;
          screenneedsupdate = true;
          if (settingsstate == "Back") {
            settingsstate = "Led"; 

          } else if (settingsstate == "Led") {
            settingsstate = "Riftbound";
          } else if (settingsstate == "Riftbound") {
            settingsstate = "One Piece";
          } else if (settingsstate == "One Piece") {
            settingsstate = "Back";
          }
        }
        delay(50);
      } else {
        debounce = false;
      }
      

      //Selecting options
      if (digitalRead(action) == LOW) {
        if (debounceaction == false) {
          debounceaction = true;
          screenneedsupdate = true;
          if (settingsstate == "Back") {
            state = "Default";
          } else if (settingsstate == "Led") {
            settingsstate = "LedSettings";
          } else if (settingsstate == "Riftbound") {
            settingsstate = "RiftboundSettings";
          } else if (settingsstate == "One Piece") {
            settingsstate = "One PieceSettings";
          }
        }
        delay(50);
      } else {
        debounceaction = false;
      }


      //Led options
    } else if (settingsstate == "LedSettings") {
      if (screenneedsupdate) {
        tft.fillScreen(ST77XX_BLACK);
        tft.setCursor(0, 0);
        tft.setTextColor(ST77XX_WHITE);
        tft.setTextSize(1);
        tft.println("Back");
        tft.setCursor(0, 20);
        tft.println("Led On/Off" + String(digitalRead(ledswitch) == HIGH ? "On" : "Off"));
        tft.setCursor(0, 40);
        tft.println("Color");
        tft.setCursor(0, 60);
        tft.println("Brightness");
        selectionarrows("LedSettings");
        screenneedsupdate = false;

      }
      
      
      if (digitalRead(config) == LOW) {
        if (debounce == false) {
          debounce = true;
          screenneedsupdate = true;
          if (settingsstate == "Back") {
            settingsstate = "LedOnOff"; 

          } else if (settingsstate == "LedOnOff") {
            settingsstate = "Color";
          } else if (settingsstate == "Color") {
            settingsstate = "Brightness";
          } else if (settingsstate == "Brightness") {
            settingsstate = "Back";
          }
        }
        delay(50);
      } else {
        debounce = false;
      }
      

      if (digitalRead(action) == LOW) {
        if (debounceaction == false) {
          debounceaction = true;
          screenneedsupdate = true;
          if (settingsstate == "Back") {
            settingsstate = "";
            state = "Default";
          } else if (settingsstate == "LedOnOff") {
            ledstate = !ledstate;
            digitalWrite(ledswitch, ledstate ? HIGH : LOW);
          } else if (settingsstate == "Color") {
            if (screenneedsupdate) {
              tft.fillScreen(ST77XX_BLACK);
              tft.setCursor(0, 0);
              tft.setTextColor(ST77XX_WHITE);
              tft.setTextSize(1);
              tft.println("Select Color:");
              tft.setCursor(0, 20);
              tft.println("White");
              tft.setCursor(0, 40);
              tft.println("Green");
              tft.setCursor(0, 60);
              tft.println("Blue");
              tft.setCursor(0, 80);
              tft.println("Black");
              selectionarrows("Color");
              screenneedsupdate = false;
            }
            
            
             if (digitalRead(config) == LOW) {
              if (debounce == false) {
                debounce = true;
                screenneedsupdate = true;
                if (settingsstate == "Color") {
                  settingsstate = "White";
                } else if (settingsstate == "White") {
                  settingsstate = "Green";
                } else if (settingsstate == "Green") {
                  settingsstate = "Blue";
                } else if (settingsstate == "Blue") {
                  settingsstate = "Black";
                } else if (settingsstate == "Black") {
                  settingsstate = "Color";
                }
              }
              delay(50);
            } else {
              debounce = false;
            }
            

             if (digitalRead(action) == LOW) {
              if (debounceaction == false) {
                debounceaction  = true;
                screenneedsupdate = true;
                // Handle color selection based on settingsstate
                if (settingsstate == "White") {
                  FastLED.setBrightness(180); //Full blast of white will draw too much power
                  bordercolor = CRGB::White;
                  ledsborder[0] = bordercolor;
                  FastLED.show();
                } else if (settingsstate == "Green") {
                  bordercolor = CRGB::Green;
                  ledsborder[0] = bordercolor;
                  FastLED.show();
                } else if (settingsstate == "Blue") {
                  bordercolor = CRGB::Blue;
                  ledsborder[0] = bordercolor;
                  FastLED.show();
                } else if (settingsstate == "Black") {
                  bordercolor = CRGB::Black;
                  FastLED.setBrightness(0);
                  FastLED.show();
                }
              }
              delay(50);
            } else {
              debounceaction = false;
            }



            // Handle color change
          } else if (settingsstate == "Brightness") {
            // Handle brightness change
            if (screenneedsupdate) {
              tft.fillScreen(ST77XX_BLACK);
              tft.setCursor(0, 0);
              tft.setTextColor(ST77XX_WHITE);
              tft.setTextSize(1);
              tft.println("Select Brightness:");
              tft.setCursor(0, 20);
              tft.println("Low");
              tft.setCursor(0, 40);
              tft.println("Medium");
              tft.setCursor(0, 60);
              tft.println("High");
              screenneedsupdate = false;
            }
            
            
             if (digitalRead(config) == LOW) {
              if (debounce == false) {
                debounce = true;
                screenneedsupdate = true;
                if (settingsstate == "Brightness") {
                  settingsstate = "Low";
                } else if (settingsstate == "Low") {
                  settingsstate = "Medium";
                } else if (settingsstate == "Medium") {
                  settingsstate = "High";
                } else if (settingsstate == "High") {
                  settingsstate = "Brightness";
                }
              }
              delay(50);
            } else {
              debounce = false;
            }

             if (digitalRead(action) == LOW) {
              if (debounceaction == false) {
                debounceaction = true;
                screenneedsupdate = true;
                // Handle brightness selection based on settingsstate
                if (settingsstate == "Low") {
                  FastLED.setBrightness(50);
                  FastLED.show();
                } else if (settingsstate == "Medium") {
                  FastLED.setBrightness(128);
                  FastLED.show();
                } else if (settingsstate == "High") {
                  if (bordercolor == CRGB::White) {
                    FastLED.setBrightness(180); //Full blast of white will draw too much power
                    bordercolor = CRGB::Black; //Reset border color so that if the user goes back to white, it will be at the correct brightness
                  } else {
                    FastLED.setBrightness(255);
                  }
                  
                  FastLED.show();
                }
              }
              delay(50);
            } else {
              debounceaction = false;
            }
        } else {
          debounce = false;
        }
      }
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

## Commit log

2026-05-16 Rename TCGMat Bill of Materials - Sheet1.csv to BOM.csv
    [BOM.csv]
2026-05-20 Rename TCGMat Bill of Materials - Sheet1 (1).csv to BOM.csv
    [BOM.csv]
2026-05-20 Rename TCGMat Bill of Materials - Sheet1 (2).csv to BOM.csv
    [BOM.csv]
